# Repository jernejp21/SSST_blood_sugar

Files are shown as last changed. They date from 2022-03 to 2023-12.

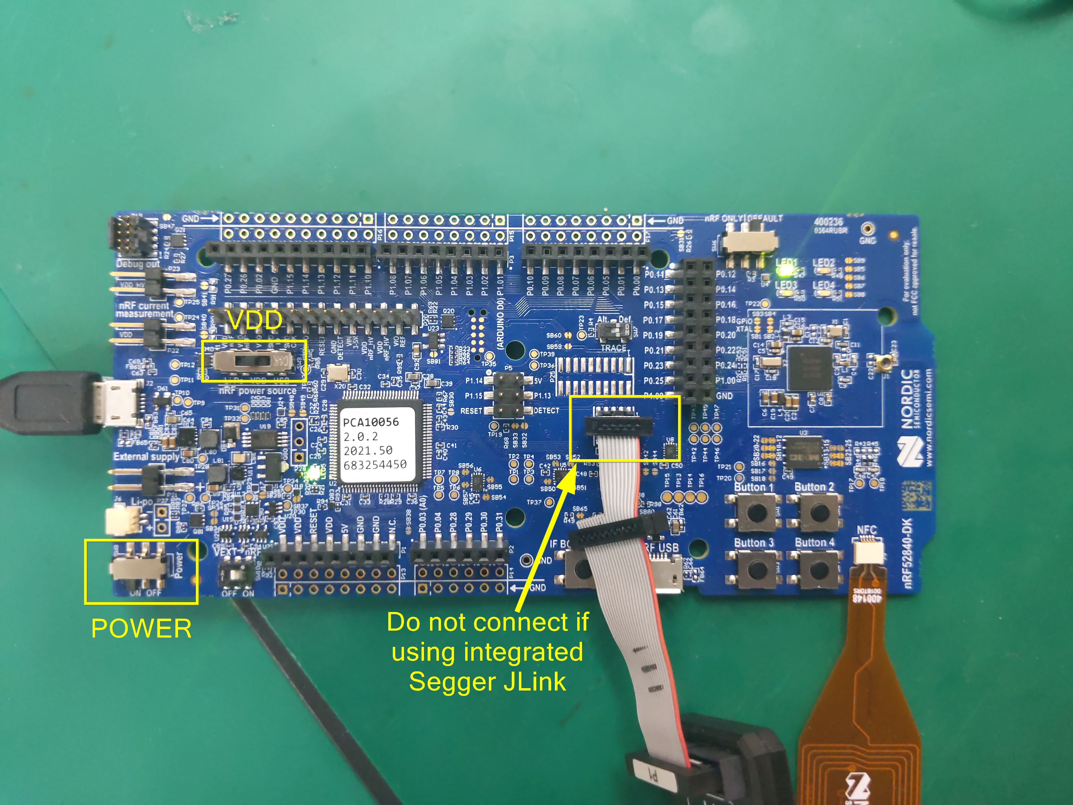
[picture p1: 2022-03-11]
Pics/nRF52840DK.jpg

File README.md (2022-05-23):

# SSST_blood_sugar

Wearable device for measuring blood sugar without analysing the blood or piecing the skin.

## SDK Installation

[Video instructions](https://youtube.com/playlist?list=PLx_tBuQ_KSqEt7NK-H7Lu78lT2OijwIMl)

Windows:
1. Install nRF Command Line Tools ([Download](https://bit.ly/2YgBGC5))
2. Install nRF Connect SDK through the Toolchain Manager in nRF Connect for Desktop ([Download](https://bit.ly/39Tm3my))
3. Install Visual Studio Code ([Download](https://code.visualstudio.com/Download))
4. **Make sure to install SDK version 1.9.0!**

## Development setup

1. After cloning git repository, open `Firmware.code-workspace` with VS Code.
2. Go to nRF Connect and create *build configuration*. Under APPLICATIONS add build configuration to Firmware.
   - Board: `nrf52840dk_nrf52840`
   - Build directory name: `build`
   - Enable debug options

3. Check `Pics/nRF52840DK.jpg` for how to connect power and debugger to development kit.

For API and how to, check [Nordic's developer website](https://developer.nordicsemi.com/nRF_Connect_SDK/doc/1.9.0/nrf/index.html).

### Git commit prefixes
When committing, use prefix for easier changelog generation.

Good example: `<prefix>: <Issue title>`

Bad example: `Fixed this and this with this commit`

Prefixes:
- `enh` for enhancement (new feature)
- `bug` for bug fixes
- `hw` for HW update
- `ref` for code refactoring

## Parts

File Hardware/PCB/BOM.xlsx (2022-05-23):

Comment | Description | Designator | Footprint | LibRef | Quantity | 代替品
GRM155R60J106ME15D | セラコン1005サイズ | C1, C7, C8, C14, C15 | C1005 | C1005 | 5
GRM188R72A104MA35D | セラコン1608サイズ | C2, C18, C19 | C1608 | C1608 | 3
GRM155R61A475MEAAD | セラコン1005サイズ | C3, C4, C9, C10, C11, C16 | C1005 | C1005 | 6
GRM155R61A224KE19J | セラコン1005サイズ | C5, C12 | C1005 | C1005 | 2
GRM155R61A102KA01D | セラコン1005サイズ | C6, C13 | C1005 | C1005 | 2
GRM155R61A104KA01J | セラコン1005サイズ | C17, C20, C21, C22 | C1005 | C1005 | 4
GRM188D71A106KA73D | セラコン1608サイズ | C23 | C1608 | C1608 | 1
CDBW0520L-G | Schottky Rectifier | D1, D5 | SOD-123 | CDBW0520L-G | 2
BAT54SHE3-TP | ダブル直列ショットキー | D2, D3, D4 | SOT-23 | BAT54S | 3
B02B-PASK-1 | 雄,ストレート,1列2ピン | J1 | B02B-PASK-1 | B02B-PASK-1 | 1
WP710A10QBC/D | LED T1 GREEN | LED1 | LED_T1 | WP710A10GD | 1
EALP03RDHRGA1 | 2色LED（赤,青） | LED2 | LED3COLORS | OSRGHC3131A | 1
FTSH-110-01-F-DV-K-P-TR | Header, 2 x 10 -Pin 1.27mm | P1 | Headerpin 2x10 | FTSH-110-01-F-DV-K-P-TR | 1
1206L016WR | Resettable PTC | PTC1 | 1206L | 1206L | 1
RG1608P-114-B-T5 | 薄膜チップ抵抗1608サイズ | R1, R21, R24 | R1608 | MF1608 | 3
RT0603BRE0710KL | 薄膜チップ抵抗1608サイズ | R2, R10 | R1608 | MF1608 | 2
RT0402BRD0710KL | 薄膜チップ抵抗1005サイズ | R3, R6, R11 | R1005 | MF1005 | 3
RG1005P-512-B-T5 | 薄膜チップ抵抗1005サイズ | R4, R5 | R1005 | MF1005 | 2
RT0402BRD073K3L | 薄膜チップ抵抗1005サイズ | R7, R8 | R1005 | MF1005 | 2
SM-3TW502 | CERMET TRIMMER 11 turns Top adjustmet | R12 | SM-3TW | SM-3TW*** | 1
RT0603CRE071KL | 薄膜チップ抵抗1608サイズ | R14 | R1608 | MF1608 | 1
RT0603DRD071ML | 薄膜チップ抵抗1608サイズ | R17 | R1608 | MF1608 | 1
RT0603DRD07200KL | 薄膜チップ抵抗1608サイズ | R18 | R1608 | MF1608 | 1
RT0603BRE0730KL | 薄膜チップ抵抗1608サイズ | R20, R23 | R1608 | MF1608 | 2
PTS645SK95SMTR92LFS | Tactile Switch 6 x 6mm | SW1, SW2 | PTS645SK13SMTR92LFS | PTS645SK13SMTR92LFS | 2
CLB2032BUPB | CLB電池ユニット ピンタイプ | U1 | CLB2032BUPB | CLB2032BUPB | 1
LTC1682IS8-3.3#PBF | IC REG CHARGE PUMP 3.3V 8SOIC | U2 | SOIC8_3.9mm | LTC1682IS8-3.3#PBF | 1
LTC1682IS8-5#PBF | IC REG CHARGE PUMP 5V MSOP8 | U3 | SOIC8_3.9mm | LTC1682IS8-5#PBF | 1
NINA-B302 | u-blox NINA-B302 Bluetooth 5 LE, 802.15.4 module | U4 | NINA_LGA67R_1500X1000X338_PIFA | NINA-B302 | 1 | NINA-B306
AD7680BRJZ | 16bit ADC 2.5V～5.5V SOT23 | U5 | SOT-23-6 | AD7680BRJZ | 1
OPA2330AIDR | CMOS ゼロドリフトアンプ 2回路 レールツーレール 8SOIC | U6 | SOIC8_3.9mm | OPA2330AIDR | 1
DX07W024JA1R1000 | USB3.1 Type-C | USB1 | DX07W024JA1R1000 | DX07W024JA1R1000 | 1

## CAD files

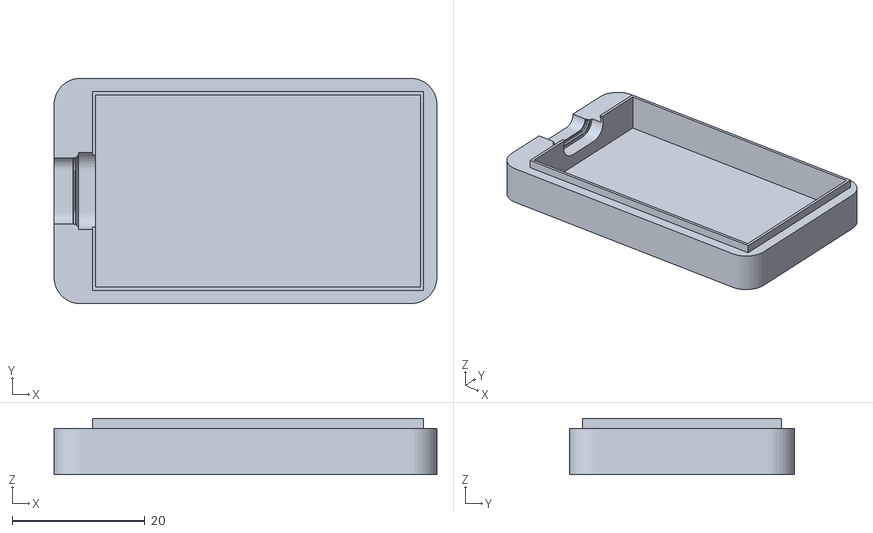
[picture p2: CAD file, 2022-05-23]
Hardware/Models/Bottom_half.stl
57.8 x 34.0 x 8.49

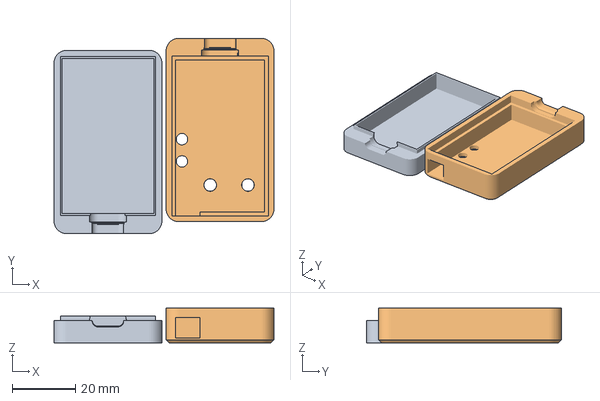
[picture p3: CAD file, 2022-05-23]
Hardware/Models/Case.3mf
69.3 x 61.6 x 11.0 mm
Bottom_half.stl
Top_half.stl

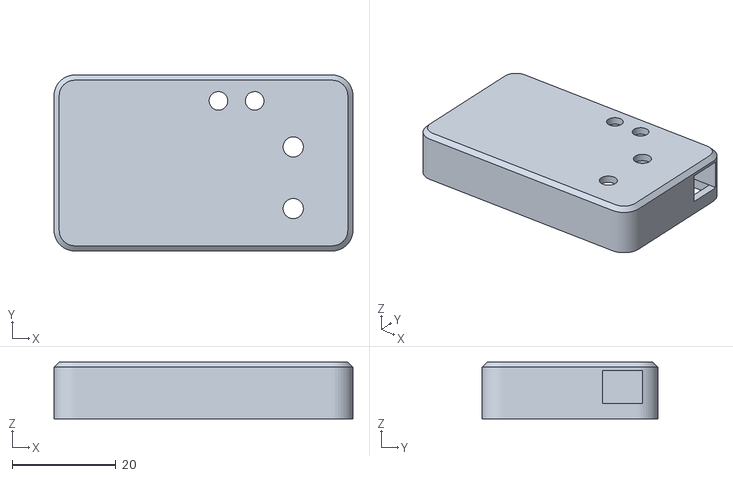
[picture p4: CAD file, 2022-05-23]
Hardware/Models/Top_half.stl
57.8 x 34.0 x 11.0

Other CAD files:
Hardware/Models/Case_v1.f3z

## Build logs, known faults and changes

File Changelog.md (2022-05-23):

# Changelog

## [HW_v1](https://github.com/AZURTEST-CORP/SSST_blood_sugar/tree/HW_v1) (2022-05-23)

[Full Changelog](https://github.com/AZURTEST-CORP/SSST_blood_sugar/compare/FW_v1...HW_v1)

**Closed issues:**

- Two V1 schematics [\#18](https://github.com/AZURTEST-CORP/SSST_blood_sugar/issues/18)
- Case for PCB [\#17](https://github.com/AZURTEST-CORP/SSST_blood_sugar/issues/17)

**Merged pull requests:**

- HW version 1 [\#27](https://github.com/AZURTEST-CORP/SSST_blood_sugar/pull/27) ([jernejp21](https://github.com/jernejp21))

## [FW_v1](https://github.com/AZURTEST-CORP/SSST_blood_sugar/tree/FW_v1) (2022-04-29)

[Full Changelog](https://github.com/AZURTEST-CORP/SSST_blood_sugar/compare/v0...FW_v1)

**Implemented enhancements:**

- Switching between external and internal ADC [\#19](https://github.com/AZURTEST-CORP/SSST_blood_sugar/issues/19)
- Implement BLE streaming [\#2](https://github.com/AZURTEST-CORP/SSST_blood_sugar/issues/2)

**Fixed bugs:**

- ADC switching wile BLE not established [\#21](https://github.com/AZURTEST-CORP/SSST_blood_sugar/issues/21)
- ABS value conversion not working [\#20](https://github.com/AZURTEST-CORP/SSST_blood_sugar/issues/20)

**Merged pull requests:**

- Milestone V1 [\#22](https://github.com/AZURTEST-CORP/SSST_blood_sugar/pull/22) ([jernejp21](https://github.com/jernejp21))

## [v0](https://github.com/AZURTEST-CORP/SSST_blood_sugar/tree/v0) (2022-04-07)

[Full Changelog](https://github.com/AZURTEST-CORP/SSST_blood_sugar/compare/35cff00ba6ae8f5cf1055288acc48ba81a52e7a6...v0)

**Implemented enhancements:**

- External A/D converter [\#12](https://github.com/AZURTEST-CORP/SSST_blood_sugar/issues/12)
- Low battery state [\#11](https://github.com/AZURTEST-CORP/SSST_blood_sugar/issues/11)
- Application layer [\#7](https://github.com/AZURTEST-CORP/SSST_blood_sugar/issues/7)
- System init [\#6](https://github.com/AZURTEST-CORP/SSST_blood_sugar/issues/6)
- ADC switch button [\#5](https://github.com/AZURTEST-CORP/SSST_blood_sugar/issues/5)
- Shutdown button [\#4](https://github.com/AZURTEST-CORP/SSST_blood_sugar/issues/4)
- Program architecture [\#1](https://github.com/AZURTEST-CORP/SSST_blood_sugar/issues/1)

**Fixed bugs:**

- Low battery check on startup [\#13](https://github.com/AZURTEST-CORP/SSST_blood_sugar/issues/13)

**Closed issues:**

- HW schematic [\#3](https://github.com/AZURTEST-CORP/SSST_blood_sugar/issues/3)

**Merged pull requests:**

- Merge of HW branch for milestone V0 [\#16](https://github.com/AZURTEST-CORP/SSST_blood_sugar/pull/16) ([jernejp21](https://github.com/jernejp21))
- Merge of FW branch for milestone V0 [\#14](https://github.com/AZURTEST-CORP/SSST_blood_sugar/pull/14) ([jernejp21](https://github.com/jernejp21))

\* *This Changelog was automatically generated by [github_changelog_generator](https://github.com/github-changelog-generator/github-changelog-generator)*

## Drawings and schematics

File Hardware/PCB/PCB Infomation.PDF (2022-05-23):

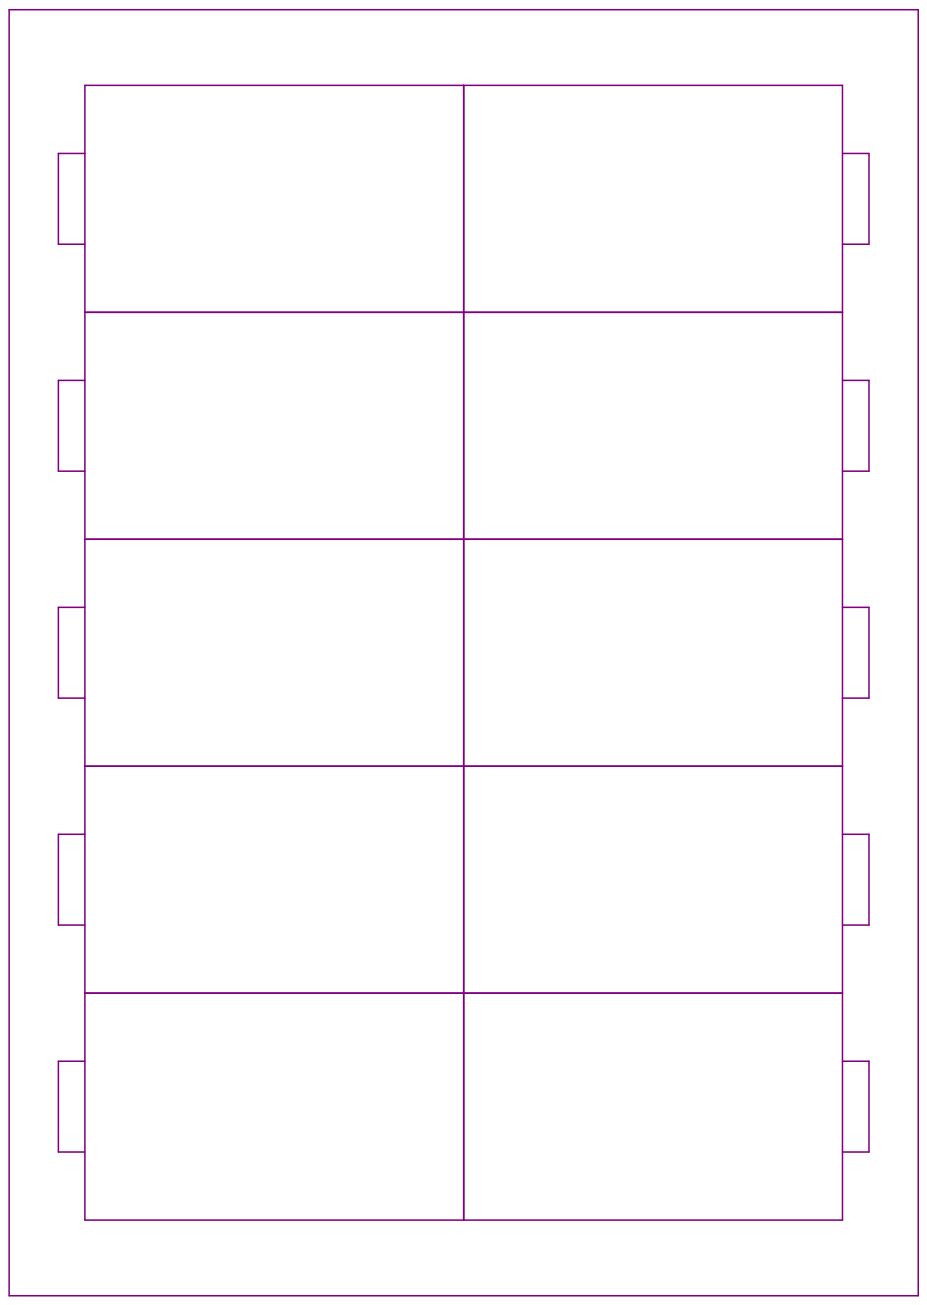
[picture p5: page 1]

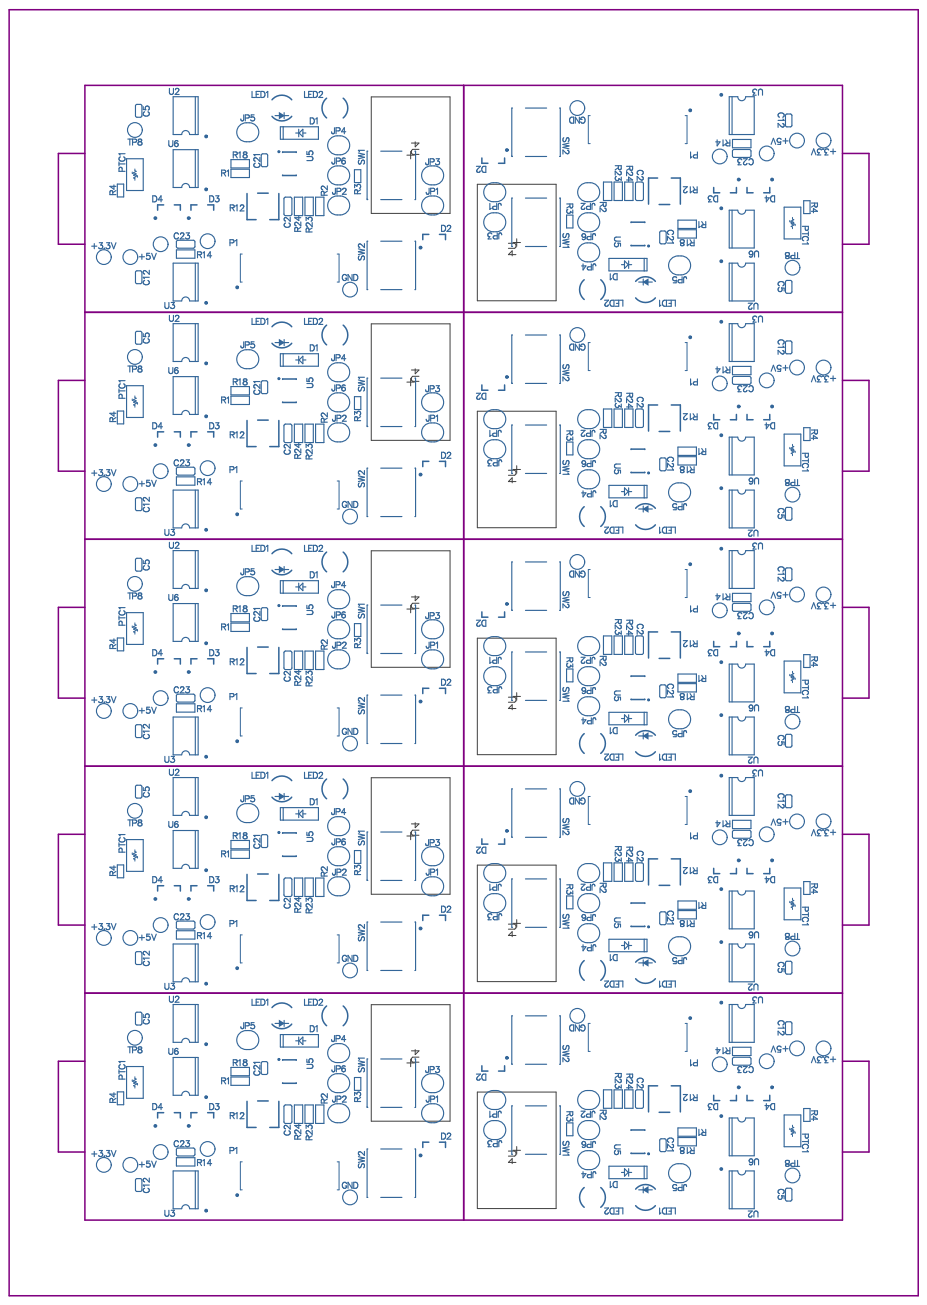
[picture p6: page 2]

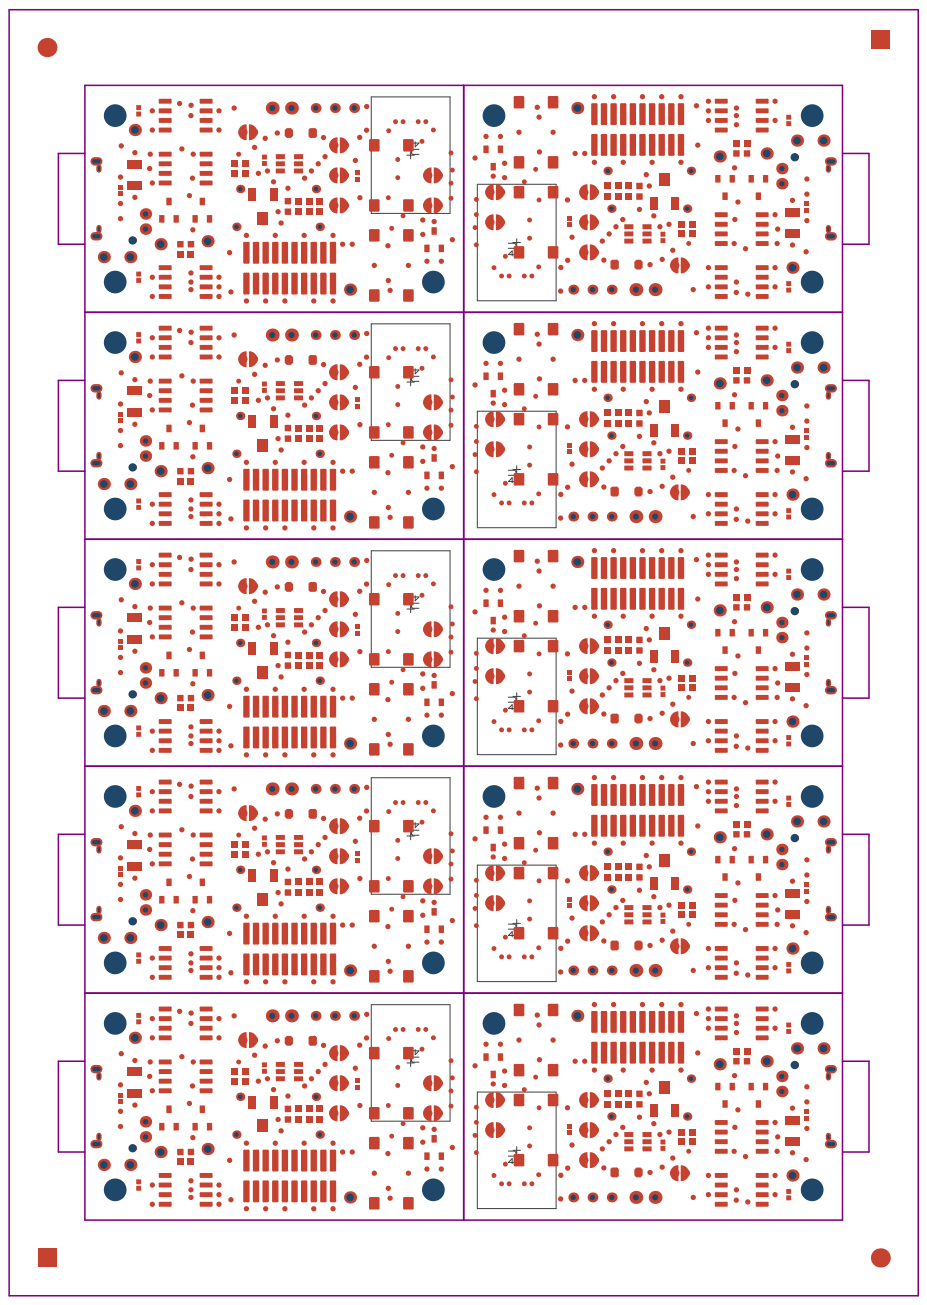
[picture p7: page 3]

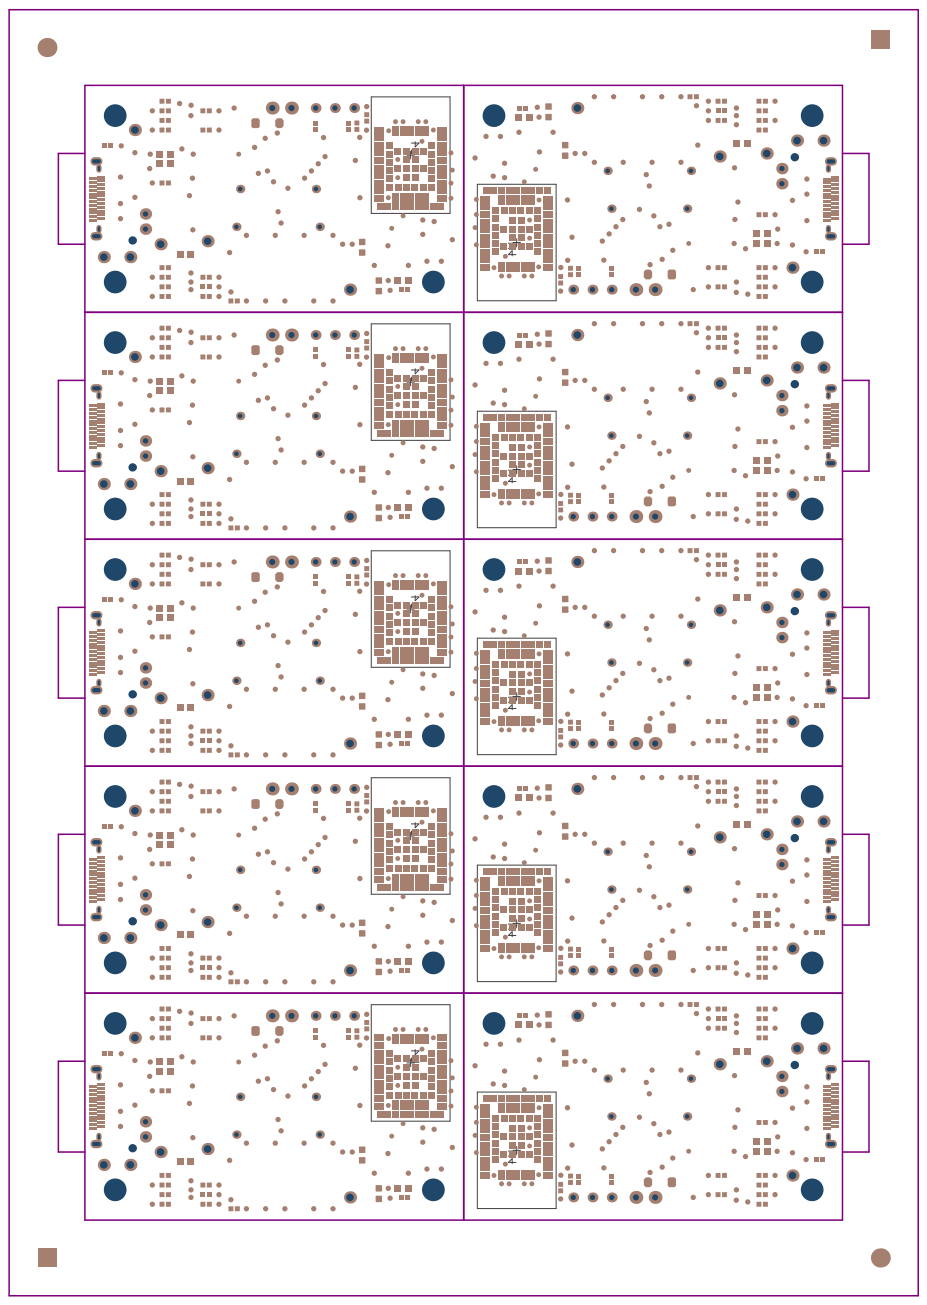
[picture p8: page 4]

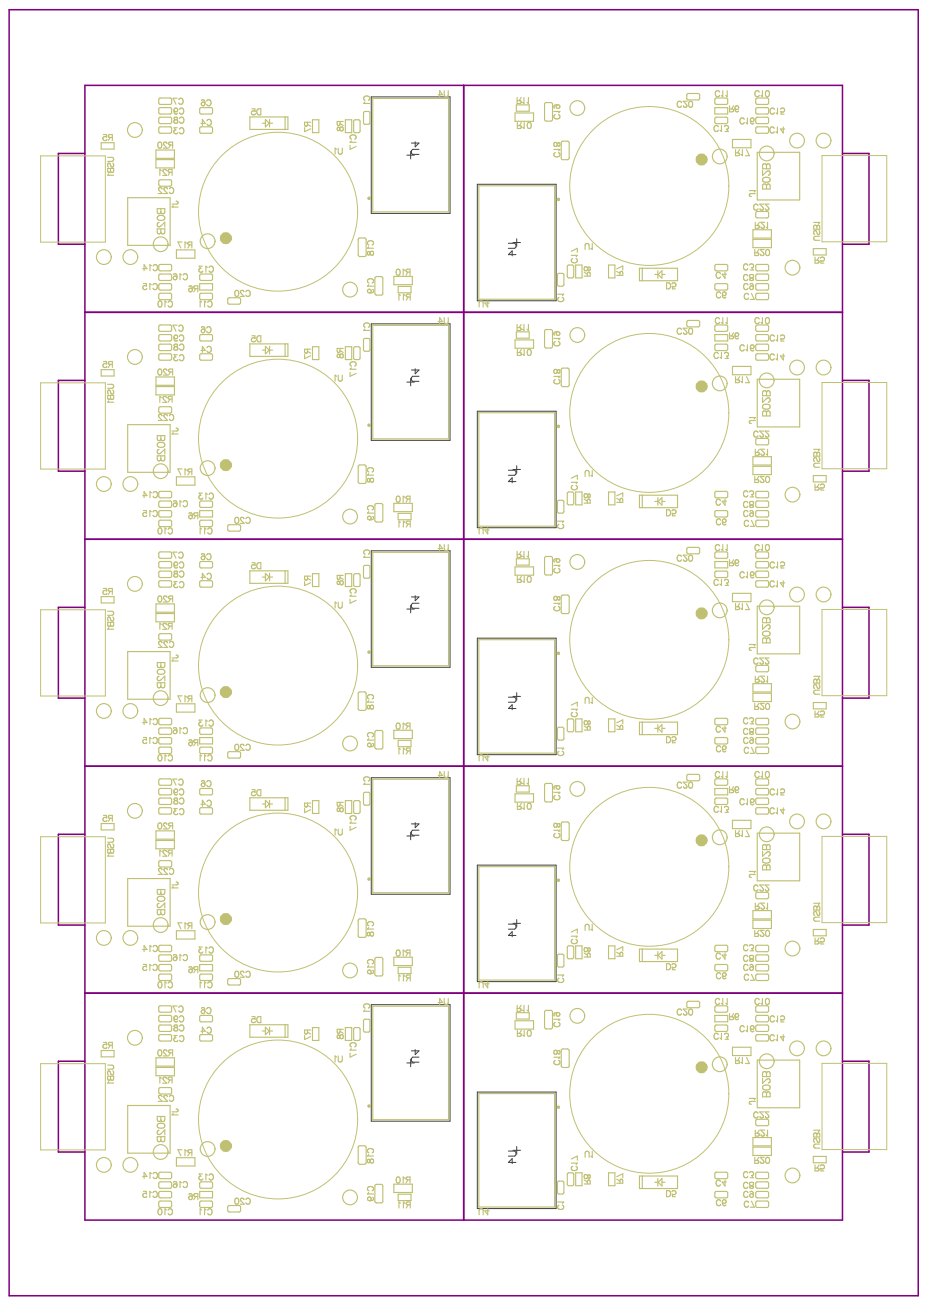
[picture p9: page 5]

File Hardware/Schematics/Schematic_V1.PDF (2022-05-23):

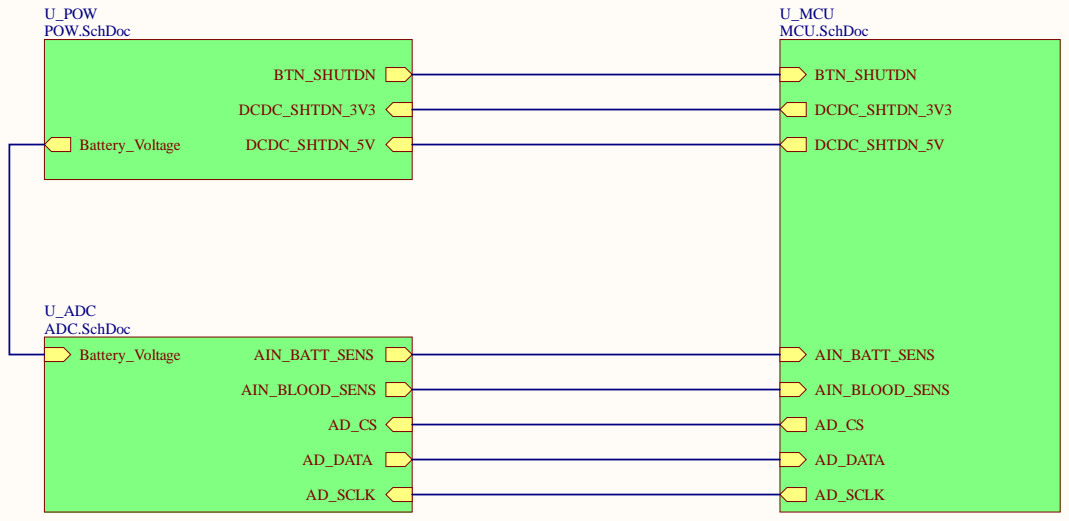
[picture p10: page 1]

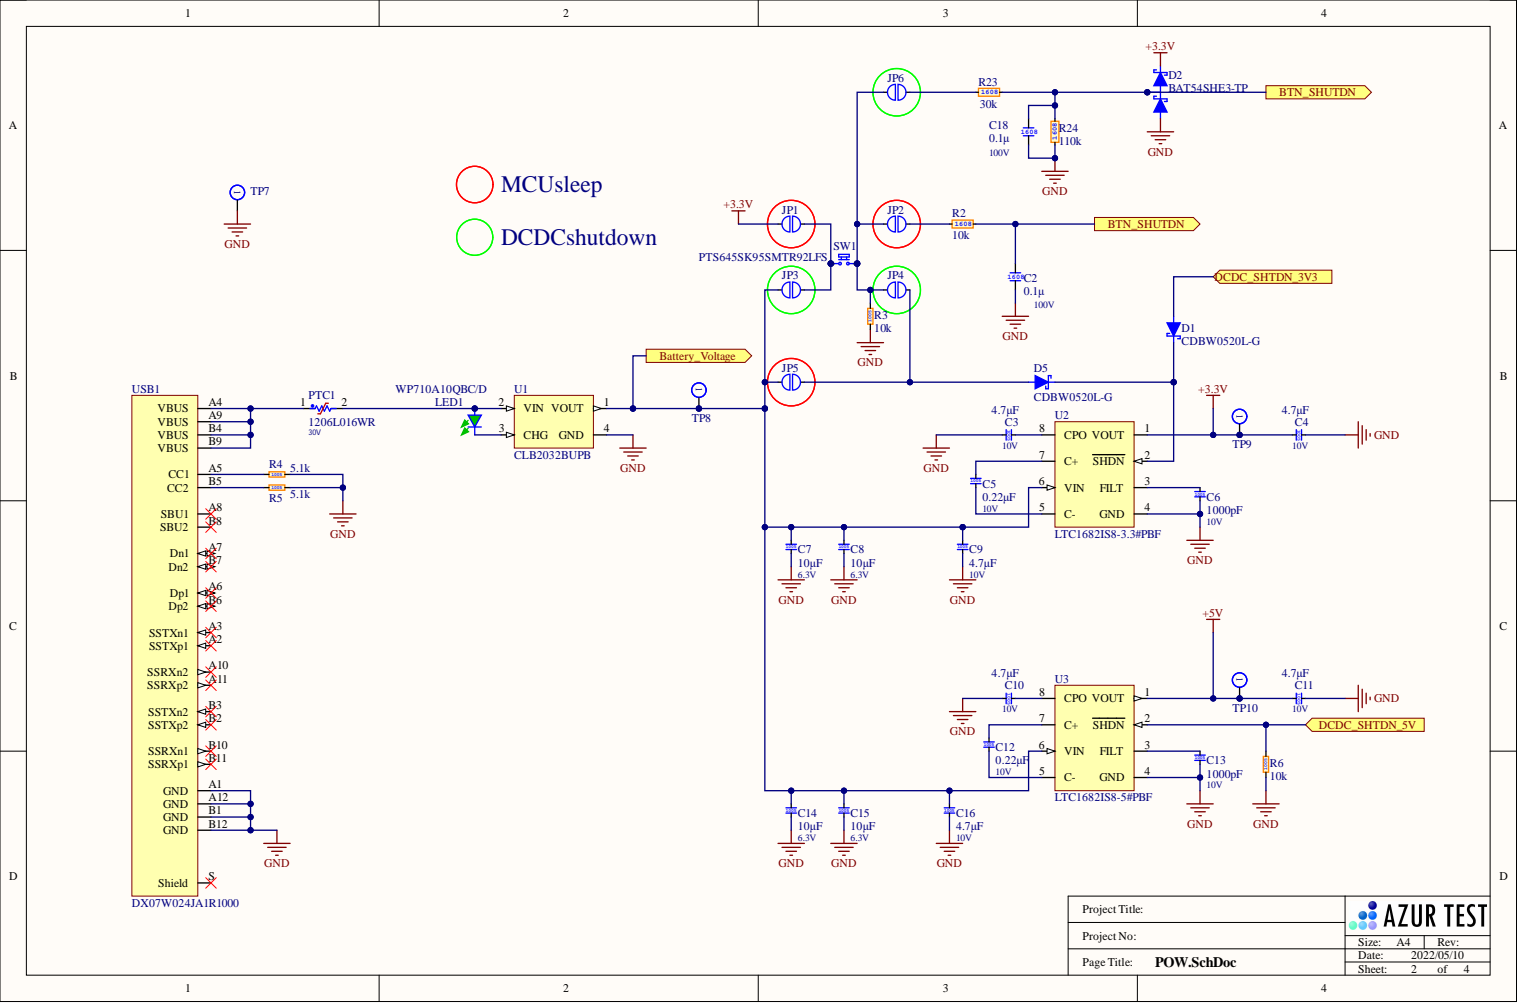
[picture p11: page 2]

VIN 6

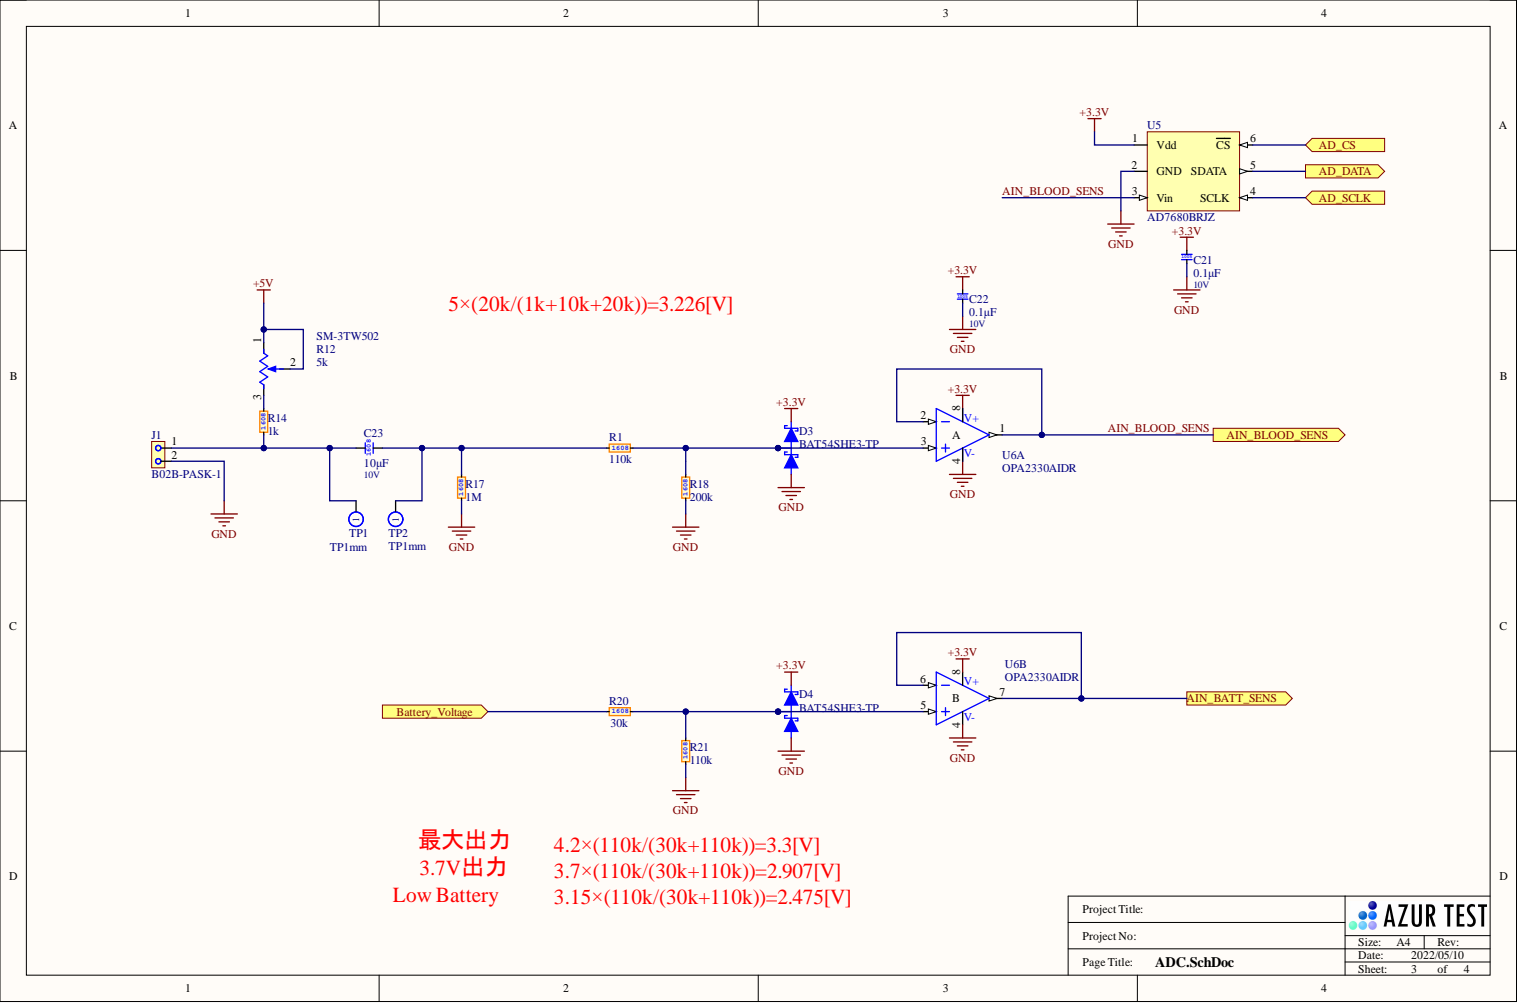
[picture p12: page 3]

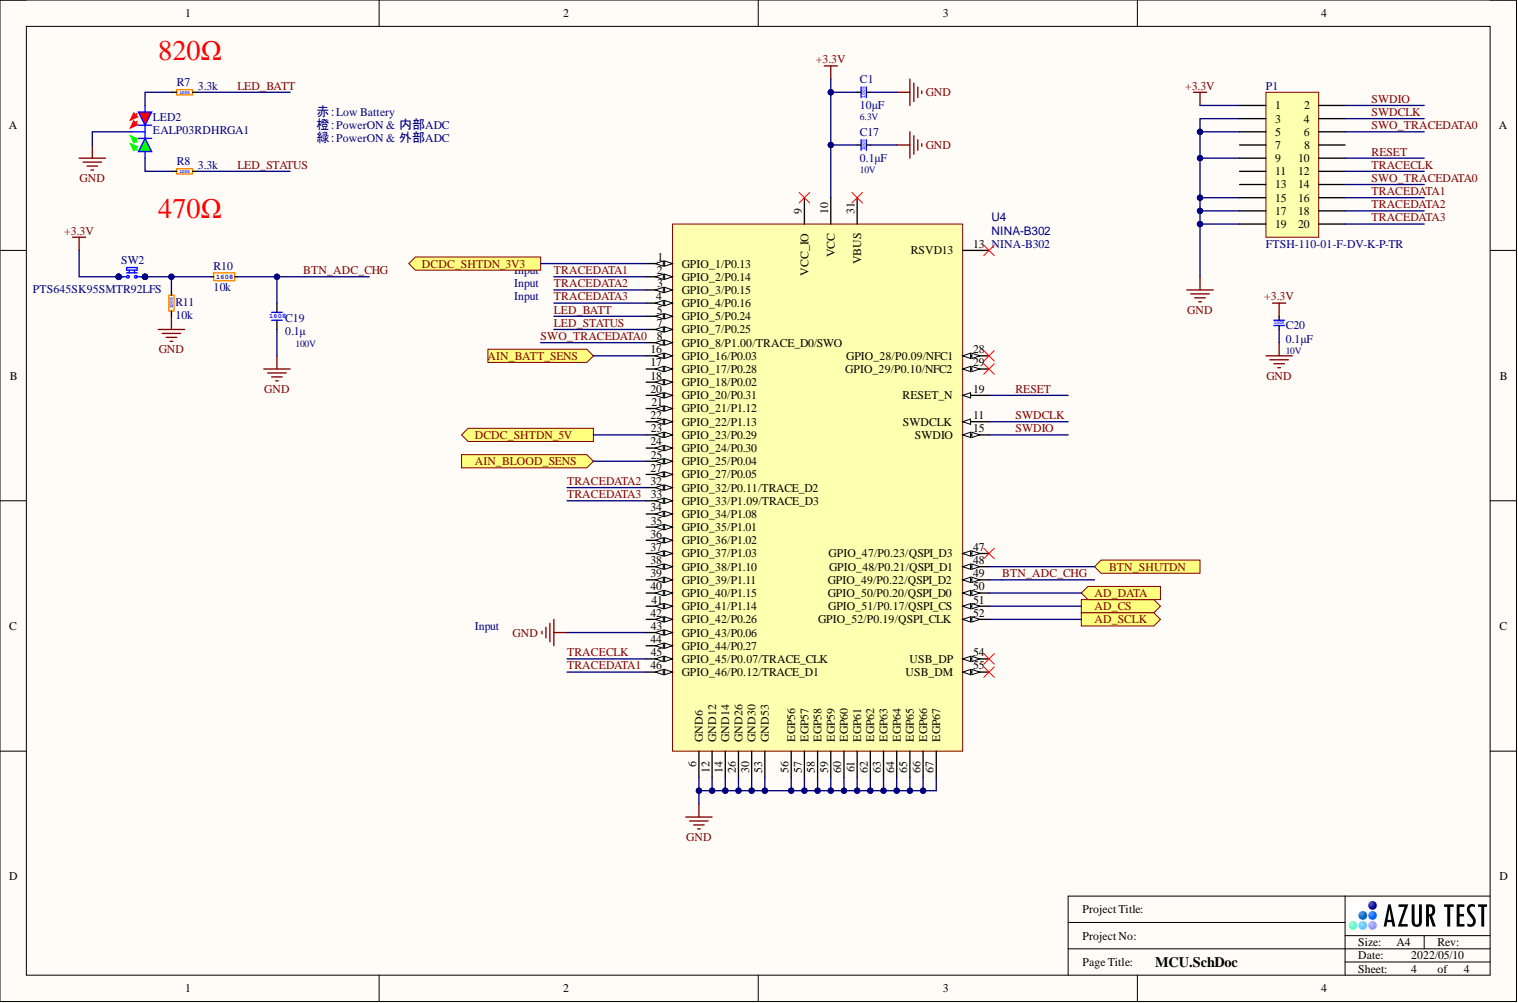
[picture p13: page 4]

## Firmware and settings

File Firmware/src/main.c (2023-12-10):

/**
 * Copyright (c) 2016 Intel Corporation
 *
 * SPDX-License-Identifier: Apache-2.0
 *
 * SSST blood sugar. Device for contacless measuring of blood sugar.
 * Copyright (C) 2022  Azurtest
 *
 * Licensed under the Apache License, Version 2.0 (the "License");
 * you may not use this file except in compliance with the License.
 * You may obtain a copy of the License at
 *
 *     http://www.apache.org/licenses/LICENSE-2.0
 *
 * Unless required by applicable law or agreed to in writing, software
 * distributed under the License is distributed on an "AS IS" BASIS,
 * WITHOUT WARRANTIES OR CONDITIONS OF ANY KIND, either express or implied.
 * See the License for the specific language governing permissions and
 * limitations under the License.
 */

#define NRF_DEFAULT_IRQ_PRIORITY 5

#include <device.h>
#include <devicetree.h>
#include <drivers/gpio.h>
#include <zephyr.h>

#include <bluetooth/bluetooth.h>
#include <bluetooth/conn.h>
#include <bluetooth/gatt.h>
#include <bluetooth/hci.h>
#include <bluetooth/uuid.h>
#include <hal/nrf_gpio.h>
#include <hal/nrf_lpcomp.h>
#include <hal/nrf_power.h>
#include <hal/nrf_ppi.h>
#include <hal/nrf_saadc.h>
#include <hal/nrf_spim.h>
#include <hal/nrf_timer.h>

#include "IO.h"
#include "config.h"

#define BT_UUID_SSST_SERVICE_VAL BT_UUID_128_ENCODE(0x0179bbd0, 0x5351, 0x48b5, 0xbf6d, 0x2167639bc867)
#define BT_UUID_SSST_DATA_VAL BT_UUID_128_ENCODE(0x0179bbd1, 0x5351, 0x48b5, 0xbf6d, 0x2167639bc867)
#define BT_UUID_SSST_STATUS_VAL BT_UUID_128_ENCODE(0x0179bbd2, 0x5351, 0x48b5, 0xbf6d, 0x2167639bc867)

#define BT_UUID_SSST_SERVICE BT_UUID_DECLARE_128(BT_UUID_SSST_SERVICE_VAL)
#define BT_UUID_SSST_DATA BT_UUID_DECLARE_128(BT_UUID_SSST_DATA_VAL)
#define BT_UUID_SSST_STATUS BT_UUID_DECLARE_128(BT_UUID_SSST_STATUS_VAL)

#define BUFFER_SIZE 3

/* Variables */
volatile uint8_t isInternalAdc;
volatile uint8_t isLowBattery;
volatile uint8_t isNotifyEnabled;
static uint16_t adcAvgData1[AVG_DATA_SIZE];
static uint16_t adcAvgData2[AVG_DATA_SIZE];
static uint16_t adcRawData[RAW_DATA_SIZE] __attribute__((aligned(2)));
static uint16_t* p_adcAvgData;
static uint8_t rx_buff[BUFFER_SIZE] __attribute__((aligned(2)));
static uint8_t tx_buff[BUFFER_SIZE] __attribute__((aligned(2)));
static uint32_t adcRawDataCnt;
static uint32_t adcAvgDataCnt;
static uint8_t statusFlags;

/* Kernel variables */
static uint8_t startShutdnTimer;
static struct k_timer shutdnTimer;
static struct k_timer ledStartupBlink;

K_THREAD_STACK_DEFINE(stk_ShutDnBtn, 1024);
struct k_thread thr_ShutDnBtn;
K_THREAD_STACK_DEFINE(stk_adcSwitchBtn, 1024);
struct k_thread thr_adcSwitchBtn;
K_THREAD_STACK_DEFINE(stk_heartBeat, 1024);
struct k_thread thr_heartBeat;
K_THREAD_STACK_DEFINE(stk_blueTooth, 1024);
struct k_thread thr_blueTooth;

K_SEM_DEFINE(bleSemaphor, 0, 1);

/* Bluetooth config */
void BT_Connected(struct bt_conn*, uint8_t);
void BT_Disconnected(struct bt_conn*, uint8_t);
ssize_t ssstStatusSend(struct bt_conn*, const struct bt_gatt_attr*, void*, uint16_t, uint16_t);
void ssst_ccc_cfg_changed(const struct bt_gatt_attr*, uint16_t);

static const struct bt_data advert[] = {
    BT_DATA_BYTES(BT_DATA_FLAGS, (BT_LE_AD_GENERAL | BT_LE_AD_NO_BREDR))};

BT_CONN_CB_DEFINE(conn_callbacks) = {
    .connected = BT_Connected,
    .disconnected = BT_Disconnected,
};

BT_GATT_SERVICE_DEFINE(ssst_svc,
                       BT_GATT_PRIMARY_SERVICE(BT_UUID_SSST_SERVICE),
                       BT_GATT_CHARACTERISTIC(BT_UUID_SSST_DATA,
                                              BT_GATT_CHRC_NOTIFY,
                                              BT_GATT_PERM_NONE,
                                              NULL, NULL, NULL),
                       BT_GATT_CCC(ssst_ccc_cfg_changed, BT_GATT_PERM_READ | BT_GATT_PERM_WRITE),
                       BT_GATT_CHARACTERISTIC(BT_UUID_SSST_STATUS,
                                              BT_GATT_CHRC_READ,
                                              BT_GATT_PERM_READ,
                                              ssstStatusSend, NULL, NULL), );

/* Functions */
static void ledExtADCSelPattern()
{
  LED_StatusOn();
  k_busy_wait(200000);
  LED_StatusOff();
}

static void ledIntADCSelPattern()
{
  LED_StatusOn();
  LED_BatteryOn();
  k_busy_wait(200000);
  LED_StatusOff();
  LED_BatteryOff();
}

static void ledLowBattery()
{
  LED_BatteryOn();
  k_busy_wait(200000);
  LED_BatteryOff();
}

extern void ledStartupBlinkCb(struct k_timer* timer_id)
{
  static int blinkCnt = 0;
  int nrOfBlinks = 6;  // 3 times on, 3 times off

  LED_StatusToggle();
  blinkCnt++;
  if(blinkCnt == nrOfBlinks)
  {
    k_timer_start(&ledStartupBlink, K_MSEC(2000), K_NO_WAIT);  // after blinks, turn on led for some time
    LED_StatusToggle();
  }
  if(blinkCnt == (nrOfBlinks + 1))
  {
    k_timer_stop(&ledStartupBlink);
    LED_StatusOff();
  }
}

extern void shutdnTimerCb(struct k_timer* timer_id)
{
  uint8_t buttonStart;
  uint8_t buttonCurrent;

  buttonStart = BTN_ShutdnStatus();

  LED_StatusOn();
  LED_BatteryOn();

  do
  {
    buttonCurrent = BTN_ShutdnStatus();
  } while(buttonStart == buttonCurrent);

  LED_StatusOff();
  LED_BatteryOff();

  DCDC_5VSwitchOff();
  DCDC_3V3SwitchOff();

  // This is needed for debugging purpose.
  k_thread_abort(&thr_adcSwitchBtn);
  k_thread_abort(&thr_blueTooth);
  k_thread_abort(&thr_heartBeat);
  k_thread_abort(&thr_ShutDnBtn);
  irq_disable(TIMER0_IRQn);
  irq_disable(TIMER1_IRQn);
  irq_disable(LPCOMP_IRQn);

  while(1)
  {
  }
}

static void resetBufferIndex()
{
  nrf_timer_event_clear(NRF_TIMER3, NRF_TIMER_EVENT_COMPARE0);
  nrf_timer_task_trigger(NRF_TIMER3, NRF_TIMER_TASK_CLEAR);
  adcRawDataCnt = 0;
  adcAvgDataCnt = 0;
}

static void adcSwitchBtn(void* p1, void* p2, void* p3)
{
  uint8_t buttonCurrStatus = BUTTON_LOGIC;
  uint8_t buttonPrevStatus = BUTTON_LOGIC;

  while(1)
  {

    buttonCurrStatus = BTN_AdcChgStatus();

    if((buttonPrevStatus != buttonCurrStatus) && (buttonCurrStatus == BUTTON_LOGIC))
    {
      timerStopSampling();
      k_sem_take(&bleSemaphor, K_NO_WAIT);

      // Switch between internal and external ADC. Interrupt
      if(isInternalAdc == 1)
      {
        // Switch to external ADC
        SAADC_DisableIntADC();
        ledExtADCSelPattern();
        SAADC_EnableExtADC(rx_buff, tx_buff, BUFFER_SIZE);

        statusFlags &= ~(1 << FLAG_SENS_BIT);
        isInternalAdc = 0;
      }
      else
      {
        // Switch to internal ADC
        SAADC_DisableExtADC();
        ledIntADCSelPattern();
        SAADC_EnableIntADC();

        statusFlags |= (1 << FLAG_SENS_BIT);
        isInternalAdc = 1;
      }

      resetBufferIndex();
      if(isNotifyEnabled == 1)
      {
        nrf_timer_task_trigger(NRF_TIMER2, NRF_TIMER_TASK_START);
      }
    }

    buttonPrevStatus = buttonCurrStatus;

    k_sleep(K_MSEC(50));
  }
}

static void shutDnBtn(void* p1, void* p2, void* p3)
{
  uint8_t buttonCurrStatus = BUTTON_LOGIC;
  uint8_t buttonPrevStatus = BUTTON_LOGIC;

  while(1)
  {

    buttonCurrStatus = BTN_ShutdnStatus();

    if(buttonPrevStatus != buttonCurrStatus)
    {
      // Button pressed or released
      if(startShutdnTimer == 0)
      {
        // Button pressed; start timer
        // When timer runs out, shutdnTimerCb is called.
        k_timer_start(&shutdnTimer, K_MSEC(BTN_SHUTDN_DELAY), K_NO_WAIT);
        startShutdnTimer = 1;
      }
      else
      {
        // Button released; stop timer
        k_timer_stop(&shutdnTimer);
        startShutdnTimer = 0;
      }
    }

    buttonPrevStatus = buttonCurrStatus;

    k_sleep(K_MSEC(50));
  }
}

static uint16_t adcSampleAverage(uint16_t* array, size_t size)
{
  uint32_t avg = 0;

  for(size_t index = 0; index < size; index++)
  {
    avg = avg + array[index];
  }

  avg = avg / size;

  return (uint16_t)avg;
}

static void heartBeat(void* p1, void* p2, void* p3)
{
  void (*hbPattern)();

  while(1)
  {
    if(isLowBattery == 1)
    {
      hbPattern = ledLowBattery;
    }
    else
    {
      if(isInternalAdc == 1)
      {
        hbPattern = ledIntADCSelPattern;
      }
      else
      {
        hbPattern = ledExtADCSelPattern;
      }
    }

    hbPattern();
    k_sleep(K_SECONDS(5));
  }
}

void BT_Connected(struct bt_conn* conn, uint8_t err)
{
}

void BT_Disconnected(struct bt_conn* conn, uint8_t reason)
{
  timerStopSampling();
  k_sem_take(&bleSemaphor, K_NO_WAIT);
  resetBufferIndex();
}

ssize_t ssstStatusSend(struct bt_conn* conn,
                       const struct bt_gatt_attr* attr,
                       void* buf,
                       uint16_t len,
                       uint16_t offset)
{
  return bt_gatt_attr_read(conn, attr, buf, len, offset, &statusFlags, sizeof(statusFlags));
}

void ssst_ccc_cfg_changed(const struct bt_gatt_attr* attr, uint16_t value)
{
  switch(value)
  {
  case 0:
    // Stop reading data from sensor
    nrf_timer_task_trigger(NRF_TIMER2, NRF_TIMER_TASK_STOP);
    k_sem_take(&bleSemaphor, K_NO_WAIT);
    resetBufferIndex();
    isNotifyEnabled = 0;
    break;

  case BT_GATT_CCC_NOTIFY:
    // Start reading data from sensor
    nrf_timer_task_trigger(NRF_TIMER2, NRF_TIMER_TASK_START);
    isNotifyEnabled = 1;
    break;

  default:
    break;
  }
}

static void BT_SendData(void* p1, void* p2, void* p3)
{
  int error;

  while(1)
  {

    k_sem_take(&bleSemaphor, K_FOREVER);

    if(p_adcAvgData == adcAvgData1)
    {
      error = bt_gatt_notify(NULL, &ssst_svc.attrs[1], adcAvgData2, AVG_DATA_SIZE * sizeof(uint16_t));
    }
    else
    {
      error = bt_gatt_notify(NULL, &ssst_svc.attrs[1], adcAvgData1, AVG_DATA_SIZE * sizeof(uint16_t));
    }
  }
}

static void LED_Init()
{
  nrf_gpio_cfg_output(LED_STATUS);
  nrf_gpio_cfg_output(LED_BATT);
  LED_StatusOff();
  LED_BatteryOff();
}

static void BTN_Init()
{
  nrf_gpio_cfg_input(BTN_SHUTDN, NRF_GPIO_PIN_NOPULL);
  nrf_gpio_cfg_input(BTN_ADC_CHG, NRF_GPIO_PIN_NOPULL);
}

static void GPIO_Init()
{
  DCDC_3V3SwitchOn();
  DCDC_5VSwitchOn();
  nrf_gpio_cfg_output(DCDC_SHTDN_3V3);
  nrf_gpio_cfg_output(DCDC_SHTDN_5V);
}

static void TIMER_Init()
{
  /* Init TIMER0 as timer */
  nrf_timer_bit_width_set(NRF_TIMER2, NRF_TIMER_BIT_WIDTH_32);
  nrf_timer_cc_set(NRF_TIMER2, NRF_TIMER_CC_CHANNEL0, SAMPLING_RATE);
  nrf_timer_int_enable(NRF_TIMER2, NRF_TIMER_INT_COMPARE0_MASK);
  nrf_timer_shorts_set(NRF_TIMER2, NRF_TIMER_SHORT_COMPARE0_CLEAR_MASK);

  /* Init TIMER1 as counter */
  nrf_timer_mode_set(NRF_TIMER3, NRF_TIMER_MODE_LOW_POWER_COUNTER);
  nrf_timer_bit_width_set(NRF_TIMER3, NRF_TIMER_BIT_WIDTH_8);
  nrf_timer_cc_set(NRF_TIMER3, NRF_TIMER_CC_CHANNEL0, RAW_DATA_SIZE);
  nrf_timer_int_enable(NRF_TIMER3, NRF_TIMER_INT_COMPARE0_MASK);
}

static void SPIM_Init()
{
  nrf_spim_configure(NRF_SPIM3, NRF_SPIM_MODE_2, NRF_SPIM_BIT_ORDER_MSB_FIRST);
  nrf_spim_pins_set(NRF_SPIM3, SPI_SCK_PIN, SPI_MOSI_PIN, SPI_MISO_PIN);
  nrf_spim_csn_configure(NRF_SPIM3, SPI_CS_PIN, NRF_SPIM_CSN_POL_LOW, 2);
  nrf_spim_frequency_set(NRF_SPIM3, NRF_SPIM_FREQ_1M);
  nrf_spim_rx_buffer_set(NRF_SPIM3, rx_buff, BUFFER_SIZE);
  nrf_spim_tx_buffer_set(NRF_SPIM3, tx_buff, BUFFER_SIZE);
  nrf_spim_enable(NRF_SPIM3);
}

static void SAADC_Init()
{
  nrf_saadc_channel_config_t config;
  config.acq_time = NRF_SAADC_ACQTIME_40US;
  config.burst = NRF_SAADC_BURST_DISABLED;
  config.gain = NRF_SAADC_GAIN1_4;
  config.mode = NRF_SAADC_MODE_SINGLE_ENDED;
  config.reference = NRF_SAADC_REFERENCE_VDD4;
  config.resistor_p = NRF_SAADC_RESISTOR_DISABLED;
  config.resistor_n = NRF_SAADC_RESISTOR_DISABLED;

  nrf_saadc_channel_init(NRF_SAADC, 0, &config);
  nrf_saadc_channel_input_set(NRF_SAADC, 0, NRF_SAADC_INPUT_AIN2, NRF_SAADC_INPUT_DISABLED);
  nrf_saadc_buffer_init(NRF_SAADC, (int16_t*)rx_buff, 1);
  nrf_saadc_resolution_set(NRF_SAADC, NRF_SAADC_RESOLUTION_12BIT);
  // nrf_saadc_int_enable(NRF_SAADC, NRF_SAADC_INT_END);
  nrf_saadc_enable(NRF_SAADC);
  nrf_saadc_task_trigger(NRF_SAADC, NRF_SAADC_TASK_START);
}

static void LPCOMP_Init()
{
  nrf_lpcomp_config_t config;
  config.detection = NRF_LPCOMP_DETECT_CROSS;
  config.reference = NRF_LPCOMP_REF_SUPPLY_6_8;  // VDD * 12 / 16
  config.hyst = NRF_LPCOMP_HYST_ENABLED;

  nrf_lpcomp_configure(NRF_LPCOMP, &config);
  nrf_lpcomp_input_select(NRF_LPCOMP, NRF_LPCOMP_INPUT_1);
  nrf_lpcomp_int_enable(NRF_LPCOMP, NRF_LPCOMP_INT_CROSS_MASK);
  nrf_lpcomp_enable(NRF_LPCOMP);
  nrf_lpcomp_task_trigger(NRF_LPCOMP, NRF_LPCOMP_TASK_START);
}

static void BT_Init()
{
  int err;

  err = bt_le_adv_start(BT_LE_ADV_CONN_NAME, advert, ARRAY_SIZE(advert), NULL, 0);
}

static void adcSamplingIRQ(const void* arg)
{
  // Called on sampling rate. Currently it's 1000 Hz

  uint8_t status = 0;
  uint16_t compoundData;

  if(isInternalAdc == 1)
  {
    nrf_saadc_task_trigger(NRF_SAADC, NRF_SAADC_TASK_SAMPLE);
    do
    {
      status = nrf_saadc_event_check(NRF_SAADC, NRF_SAADC_EVENT_END);
    } while(status == 0);

    compoundData = (rx_buff[1] << 8) | rx_buff[0];

    // ABS value
    uint16_t tmp;
    tmp = compoundData >> 15;
    tmp = tmp ? 0xFFFF : 0;
    compoundData ^= tmp;
    compoundData += tmp & 1;
    adcRawData[adcRawDataCnt] = compoundData;

    nrf_saadc_event_clear(NRF_SAADC, NRF_SAADC_EVENT_STARTED);
    nrf_saadc_event_clear(NRF_SAADC, NRF_SAADC_EVENT_END);
    nrf_saadc_event_clear(NRF_SAADC, NRF_SAADC_EVENT_DONE);
    nrf_saadc_event_clear(NRF_SAADC, NRF_SAADC_EVENT_RESULTDONE);
    nrf_saadc_task_trigger(NRF_SAADC, NRF_SAADC_TASK_START);
  }
  else
  {
    // Sample data from external ADC via SPI
    nrf_spim_task_trigger(NRF_SPIM3, NRF_SPIM_TASK_START);
    do
    {
      status = nrf_spim_event_check(NRF_SPIM3, NRF_SPIM_EVENT_END);
    } while(status == 0);

    compoundData = (rx_buff[0] << 12) | (rx_buff[1] << 4) | (rx_buff[2] >> 4);
    adcRawData[adcRawDataCnt] = compoundData;

    nrf_spim_event_clear(NRF_SPIM3, NRF_SPIM_EVENT_END);
  }

  adcRawDataCnt++;
  nrf_timer_task_trigger(NRF_TIMER3, NRF_TIMER_TASK_COUNT);
  nrf_timer_event_clear(NRF_TIMER2, NRF_TIMER_EVENT_COMPARE0);
}

static void adcAvgIRQ(const void* arg)
{

  // Called when EasyDMA is full. Currently is on 10 samples - 100 Hz.

  adcRawDataCnt = 0;
  nrf_timer_event_clear(NRF_TIMER3, NRF_TIMER_EVENT_COMPARE0);
  nrf_timer_task_trigger(NRF_TIMER3, NRF_TIMER_TASK_CLEAR);

  p_adcAvgData[adcAvgDataCnt] = adcSampleAverage(adcRawData, RAW_DATA_SIZE);
  adcAvgDataCnt++;

  if(adcAvgDataCnt == AVG_DATA_SIZE)
  {
    // Start BT transatction
    k_sem_give(&bleSemaphor);

    // Change buffer
    if(p_adcAvgData == adcAvgData1)
    {
      p_adcAvgData = adcAvgData2;
    }
    else
    {
      p_adcAvgData = adcAvgData1;
    }

    adcAvgDataCnt = 0;
  }
}

static void checkBattStatus(const void* arg)
{
  uint8_t status;

  status = nrf_lpcomp_event_check(NRF_LPCOMP, NRF_LPCOMP_EVENT_DOWN);
  if(status == 1)
  {
    // Low battery
    isLowBattery = 1;
    statusFlags |= (1 << FLAG_BATT_BIT);
    SAADC_DisableExtADC();
    SAADC_DisableIntADC();
    k_thread_suspend(&thr_adcSwitchBtn);
  }

  status = nrf_lpcomp_event_check(NRF_LPCOMP, NRF_LPCOMP_EVENT_UP);
  if(status == 1)
  {
    // Battery is charging. No more low battery
    isLowBattery = 0;
    statusFlags &= ~(1 << FLAG_BATT_BIT);
    if(isInternalAdc == 1)
    {
      SAADC_EnableIntADC();
    }
    else
    {
      SAADC_EnableExtADC(rx_buff, tx_buff, BUFFER_SIZE);
    }

    k_thread_resume(&thr_adcSwitchBtn);
  }

  nrf_lpcomp_event_clear(NRF_LPCOMP, NRF_LPCOMP_EVENT_DOWN);
  nrf_lpcomp_event_clear(NRF_LPCOMP, NRF_LPCOMP_EVENT_UP);
  nrf_lpcomp_event_clear(NRF_LPCOMP, NRF_LPCOMP_EVENT_CROSS);
}

static void kernelInit()
{
  int priority;

  /* Init threads but don't start them yet. */
  priority = 5;
  k_thread_create(&thr_ShutDnBtn, stk_ShutDnBtn, K_THREAD_STACK_SIZEOF(stk_ShutDnBtn), shutDnBtn, NULL, NULL, NULL, priority, 0, K_MSEC(3000));
  k_thread_name_set(&thr_ShutDnBtn, "Shutdown button");

  priority = 6;
  k_thread_create(&thr_adcSwitchBtn, stk_adcSwitchBtn, K_THREAD_STACK_SIZEOF(stk_adcSwitchBtn), adcSwitchBtn, NULL, NULL, NULL, priority, 0, K_NO_WAIT);
  k_thread_name_set(&thr_adcSwitchBtn, "ADC switch button");
  k_thread_suspend(&thr_adcSwitchBtn);

  priority = 7;
  k_thread_create(&thr_heartBeat, stk_heartBeat, K_THREAD_STACK_SIZEOF(stk_heartBeat), heartBeat, NULL, NULL, NULL, priority, 0, K_MSEC(3040));
  k_thread_name_set(&thr_heartBeat, "Heartbeat");

  priority = 8;
  k_thread_create(&thr_blueTooth, stk_blueTooth, K_THREAD_STACK_SIZEOF(stk_blueTooth), BT_SendData, NULL, NULL, NULL, priority, 0, K_NO_WAIT);
  k_thread_name_set(&thr_blueTooth, "Bluetooth");

  /* Init IRQs */
  priority = -3;
  irq_connect_dynamic(TIMER2_IRQn, priority, adcSamplingIRQ, NULL, 0);
  irq_enable(TIMER2_IRQn);

  priority = -2;
  irq_connect_dynamic(TIMER3_IRQn, priority, adcAvgIRQ, NULL, 0);
  irq_enable(TIMER3_IRQn);

  priority = -4;
  irq_connect_dynamic(LPCOMP_IRQn, priority, checkBattStatus, NULL, 0);
  irq_enable(LPCOMP_IRQn);

  /* Timer init */
  k_timer_init(&shutdnTimer, shutdnTimerCb, NULL);
  k_timer_init(&ledStartupBlink, ledStartupBlinkCb, NULL);
}

static void checkStartupBattery()
{
  uint8_t status = 0;

  /* Enable SAADC on AIN5 */
  nrf_saadc_channel_config_t config;
  config.acq_time = NRF_SAADC_ACQTIME_40US;
  config.burst = NRF_SAADC_BURST_DISABLED;
  config.gain = NRF_SAADC_GAIN1_4;
  config.mode = NRF_SAADC_MODE_SINGLE_ENDED;
  config.reference = NRF_SAADC_REFERENCE_VDD4;
  config.resistor_p = NRF_SAADC_RESISTOR_DISABLED;
  config.resistor_n = NRF_SAADC_RESISTOR_DISABLED;

  nrf_saadc_channel_init(NRF_SAADC, 0, &config);
  nrf_saadc_channel_input_set(NRF_SAADC, 0, NRF_SAADC_INPUT_AIN1, NRF_SAADC_INPUT_DISABLED);
  nrf_saadc_buffer_init(NRF_SAADC, (int16_t*)rx_buff, 1);
  nrf_saadc_resolution_set(NRF_SAADC, NRF_SAADC_RESOLUTION_12BIT);
  nrf_saadc_enable(NRF_SAADC);

  /* SAADC calibration */
  nrf_saadc_task_trigger(NRF_SAADC, NRF_SAADC_TASK_CALIBRATEOFFSET);
  do
  {
    status = nrf_saadc_event_check(NRF_SAADC, NRF_SAADC_EVENT_CALIBRATEDONE);
  } while(status == 0);

  /* Start SAADC */
  nrf_saadc_task_trigger(NRF_SAADC, NRF_SAADC_TASK_START);
  do
  {
    status = nrf_saadc_event_check(NRF_SAADC, NRF_SAADC_EVENT_STARTED);
  } while(status == 0);

  /* Sample */
  nrf_saadc_task_trigger(NRF_SAADC, NRF_SAADC_TASK_SAMPLE);
  do
  {
    status = nrf_saadc_event_check(NRF_SAADC, NRF_SAADC_EVENT_END);
  } while(status == 0);

  int16_t result = (rx_buff[1] << 8) | rx_buff[0];
  float voltage = SUPPLY_VOLTAGE * (float)result / 4096;

  if(voltage > BATT_MIN_VOLT)
  {
    isInternalAdc = 0;
    isLowBattery = 0;
    statusFlags &= ~(1 << FLAG_BATT_BIT);
    SAADC_DisableIntADC();
    SAADC_EnableExtADC(rx_buff, tx_buff, BUFFER_SIZE);
    k_thread_resume(&thr_adcSwitchBtn);
  }
  else
  {
    isLowBattery = 1;
    statusFlags |= (1 << FLAG_BATT_BIT);
    SAADC_DisableExtADC();
    SAADC_DisableIntADC();
    k_thread_suspend(&thr_adcSwitchBtn);
  }

  nrf_saadc_disable(NRF_SAADC);
}

void main(void)
{
  int err;

  /* System init */
  LED_Init();
  BTN_Init();
  GPIO_Init();
  TIMER_Init();
  SPIM_Init();
  LPCOMP_Init();
  kernelInit();
  /* End of system init */

  /* Check battery status */
  checkStartupBattery();
  SAADC_Init();

  p_adcAvgData = adcAvgData1;

  /* Begin LED start-up complete sequence */
  k_timer_start(&ledStartupBlink, K_MSEC(100), K_MSEC(100));

  /* Start BT advertising */
  err = bt_enable(BT_Init);

  // main is only for system init. Afterwards everyhing is done in threads.
}

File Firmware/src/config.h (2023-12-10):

/**
 * SSST blood sugar. Device for contacless measuring of blood sugar.
 * Copyright (C) 2022  Azurtest
 *
 * Licensed under the Apache License, Version 2.0 (the "License");
 * you may not use this file except in compliance with the License.
 * You may obtain a copy of the License at
 *
 *     http://www.apache.org/licenses/LICENSE-2.0
 *
 * Unless required by applicable law or agreed to in writing, software
 * distributed under the License is distributed on an "AS IS" BASIS,
 * WITHOUT WARRANTIES OR CONDITIONS OF ANY KIND, either express or implied.
 * See the License for the specific language governing permissions and
 * limitations under the License.
 */

#ifndef __CONFIG_H
#define __CONFIG_H

/* Defines */
#define RAW_DATA_SIZE 10  // This will change after testing
#define AVG_DATA_SIZE 100  // This will change after testing
#define BTN_SHUTDN_DELAY 2500  // value in ms
#define SAMPLING_RATE 1000  // 1000000/SAMPLING_RATE is samp. freq.
#define PIN_MAP(port, pin) (port * 32 + pin)
#define FLAG_SENS_BIT 0
#define FLAG_BATT_BIT 1

/* HW defines. LEDs, Buttons etc. */
#define BTN_SHUTDN PIN_MAP(0, 21)
#define BTN_ADC_CHG PIN_MAP(0, 22)
#define LED_STATUS PIN_MAP(0, 25)
#define LED_BATT PIN_MAP(0, 24)
#define DCDC_SHTDN_3V3 PIN_MAP(0, 13)
#define DCDC_SHTDN_5V PIN_MAP(0, 29)
#define AIN_BATT_SENS PIN_MAP(0, 3)
#define AIN_BLOOD_SENS PIN_MAP(0, 4)
#define SPI_SCK_PIN PIN_MAP(0, 19)
#define SPI_MOSI_PIN PIN_MAP(0, 18)
#define SPI_MISO_PIN PIN_MAP(0, 20)
#define SPI_CS_PIN PIN_MAP(0, 17)

/* HW configuration. LOW, HIGH logic etc. */
//#define BUTTON_POS_LOGIC  // Is button positve logic? Released LOW state, pressed HIGH state
#define SUPPLY_VOLTAGE (4.2)
#define BATT_MIN_VOLT (SUPPLY_VOLTAGE * 12 / 16)  // Not actual voltage, but adjusted where full battery (about 4.2 V) is suppy voltage

#ifdef BUTTON_POS_LOGIC
#define BUTTON_LOGIC 1
#else
#define BUTTON_LOGIC 0
#endif

/* Enums */

enum
{
    ERROR_AMP = 1,
    ERROR_ADC,
    ERROR_OTH,
    ERROR_NONE = 0xFF,
};

#endif  //__CONFIG

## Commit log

2022-03-11 Project framework commit.
    Created project framework. This counts as initial commit.
2022-03-16 enh: Shutdown button #4
    Implemented shutdown sequence. When button is pressed for X seconds, device will go into power-off mode.
2022-03-18 hw: HW schematic #3
    Initial HW for SSST.
    [ADC.SchDoc, MCU.SchDoc, POW.SchDoc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]
2022-03-18 enh: Shutdown button #4
    Shutdown button function is independent of hardware.
2022-03-22 hw: HW schematic #3
    The circuit diagram has been updated.
    ・ Change of resistance constant
    ・Addition of DCDC shutdown circuit
    ・ Addition of protection circuit
    [ADC.SchDoc, BOM.xlsx, MCU.SchDoc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]
2022-03-22 Update Schematic
    ・ Change of part model name
    ・ Change of comment
    [ADC.SchDoc, BOM.xlsx, MCU.SchDoc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]
2022-03-23 enh: System init #6
    Implemented LED blink indicator after system init is done.
2022-03-23 enh: Application layer #7
    Implemented OS threads for both buttons and MCU heartbeat.
2022-03-23 hw: Schematic update
    Changed the voltage value of Low Battery.
    The low battery is notified when the battery voltage is 3.15V.
    [ADC.SchDoc]
2022-03-23 hw: Schematic PDF update
    I changed the contents of Altium, so I re-output the PDF
2022-03-29 hw: PCB v1 and change Library
    ・Now that the schematic is complete, I have created a PCB document.
    ・Fixed SCHLIB and PCBLIB. (Addition of 3D drawing)
    ・Since I modified the library, I also updated the schematic.
    [4Layer.PcbDoc, ADC.SchDoc, MCU.SchDoc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]
2022-03-29 enh: ADC switch button #5
    Added implementation for switching between internal and external ADC.
2022-03-29 enh: Low battery state #11
    Implemented low battery detection and LED indication. Bluetooth not supported.
2022-03-31 enh: External A/D converter #12
    Implemented external (SPI) ADC.
2022-03-31 ref: Low battery state #11
    Changed to HAL. Previously used direct reading and writing in register s.
2022-04-05 bug: Low battery check on startup #13
    Implemented checking for low battery on startup. Fixed a bug for enabling external ADC.
    [IO.c, config.h, main.c]
2022-04-06 hw: Initial PCB for SSST
    ・Addition of PCB_v1
    ・ Addition of imposition PCB
    ・ Creating a Gerber file
    ・ BOM update (change of part model number)
    ・Modify the library
    ・ Change the pins used in the MCU
    [4Layer.PcbDoc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]
2022-04-07 hw: PCB update & Add step file
    ・Change of silk layer
    ・Gerber reoutput
    ・Add step file
    [4Layer.PcbDoc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]
2022-04-07 hw: File name change
    ・Renamed the PCB file.
    [4Layer_Imposition.DRL, 4Layer_Imposition.GBL, 4Layer_Imposition.GBO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]
2022-04-07 hw: corrected folder structure and schematics.
2022-04-13 hw: Gerber output for mounting
    The PCB infomation file required for implementation was output.
    [BOM.xlsx]
2022-04-20 hw: BOM update
    Schematic and BOM update
    [ADC.SchDoc, BOM.xlsx, MCU.SchDoc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]
2022-04-25 hw: update Schematic PDF
    update Schematic PDF
    [MCU.SchDoc, POW.SchDoc, SSST.PcbDoc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]
2022-04-27 ref: Changed HW peripherals according to custom HW design.
    Reference issue #3 for which peripherals are used on custom board. Previous version was designed for nRF52840DK.
    [config.h, main.c]
2022-04-27 enh: Switching between external and internal ADC #19
    When switching, BLE notifications are not sent. After switching is completed, notifications start again.
2022-04-27 bug: ADC switching wile BLE not established #21
    If button is pressed, sampling starts only if BLE notifications are enabled. If disabled, only ADC changes, sampling not active.
    [main.c]
2022-04-27 hw: Remove Schematic_v1 PDF
2022-04-27 bug: ABS value conversion not working #20
    Fixed absolute value conversion.
    [main.c]
2022-05-06 #3 hw: Update Schematic Document
    Changed the constant of LED lighting resistor.
    Along with that, the PDF file has also been updated.
    [MCU.SchDoc]
2022-05-10 hw: Two V1 schematics #18
    Corrected the characters on the schematic.
    [ADC.SchDoc, MCU.SchDoc, POW.SchDoc]
2022-05-23 hw: Case for PCB #17
    Created case for PCB for 3D printing.
    [Bottom_half.stl, Case.3mf, Case_v1.f3z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]
2022-06-01 enh: Reduce power consumption #28
    Created new board so that UART can be disabled. Implemented shutting down external ADC when internal ADC is used.
2022-06-01 enh: Status flag for ADC and battery #29
    Implementation of status flags. Same function as status / battery LED.
